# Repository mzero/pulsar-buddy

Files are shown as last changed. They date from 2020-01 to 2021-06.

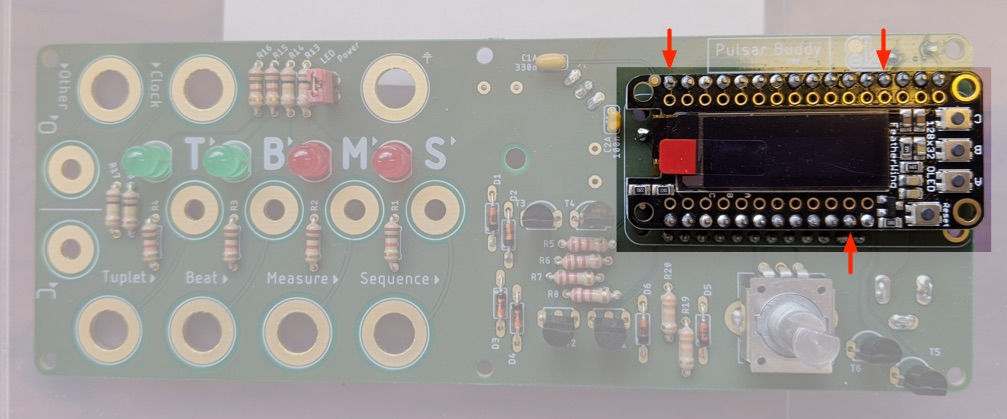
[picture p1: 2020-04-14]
wiki-images/assembly/step 5 top.jpg

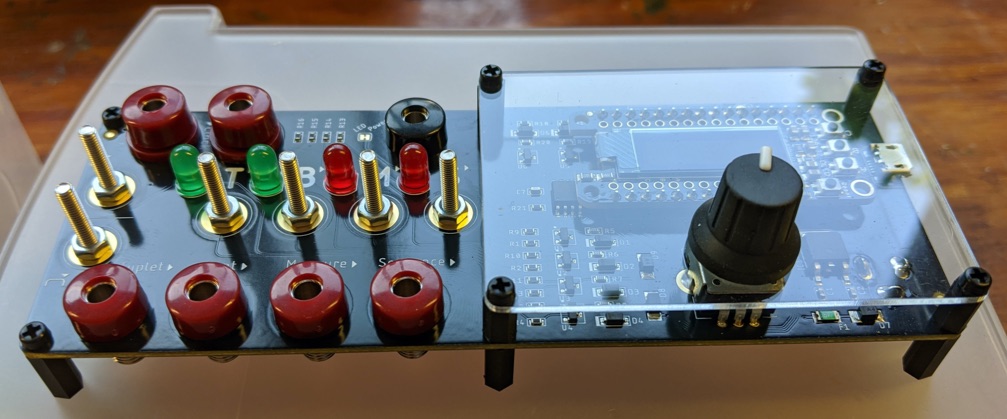
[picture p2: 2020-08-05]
wiki-images/assembly/E step 4 plate.jpg

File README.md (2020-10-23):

# Pulsar Buddy

Pulsar Buddy is a small clock unit for the SOMA Lab's Pulsar-23 synth.
It is also useful with other modular synths.

Please see the [Wiki](https://github.com/mzero/pulsar-buddy/wiki) for full
information.

----

Pulsar Buddy is open source hardware and open source software.

The hardware is licensed by CC-SA-3.0. See LICENSE-HW.txt
The software is licensed by BSD3. See LICENSE-SW.txt

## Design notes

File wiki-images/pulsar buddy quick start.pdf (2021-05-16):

# Here is your

Pulsar Buddy.

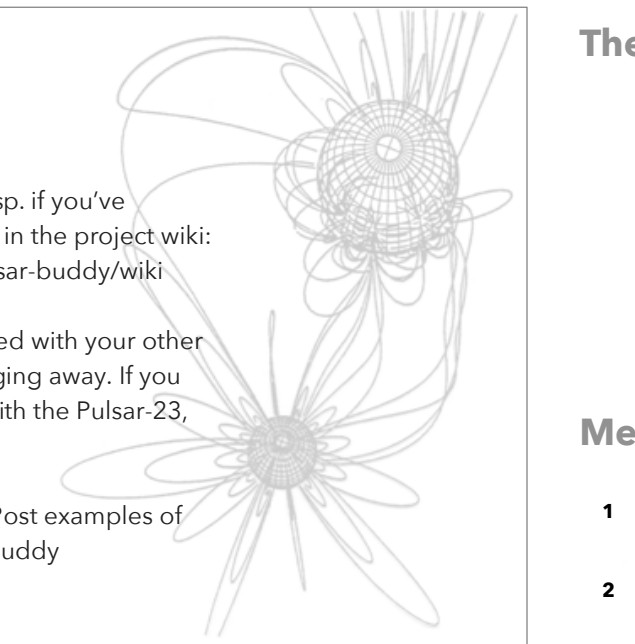
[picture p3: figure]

### It should be pretty self-evident, esp. if you’ve watched the video. The manual is in the project wiki: https://github.com/mzero/pulsar-buddy/wiki

### Make sure that the unit is grounded with your other equipment before you start plugging away. If you

use the included power splitter with the Pulsar-23, then you are good to go.

### Please let me know how it goes. Post examples of you playing with it using #pulsarbuddy

### I can’t wait to hear what you do!

# The Display

Current BPM

Measures in the sequence.
The S output triggers once per sequence.

Time signature.
The M output triggers
once per measure.

Tuplet ratio n:m.
The T output
triggers n times for
every m beats.

Tuplet base beat.
The B output
triggers once for
each base beat.

Memory slots

# Meter & Tuplets

Turn to select
a field.

Click to edit it.

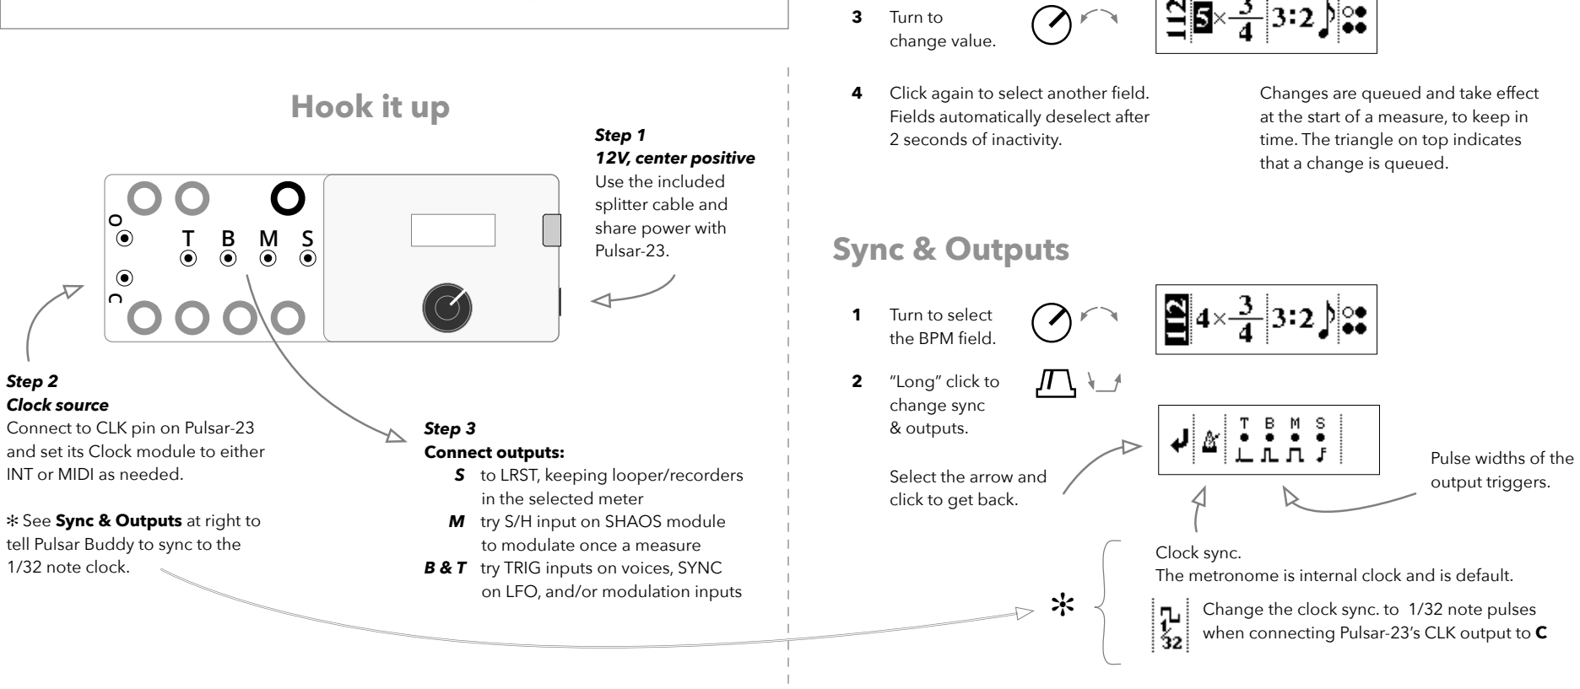
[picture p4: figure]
Hook it up; Step 1 12V, center positive Use the included splitter cable and share power with Pulsar-23.; Step 2 Clock source Connect to CLK pin on Pulsar-23 and set its Clock module to either INT or MIDI as needed.; ✻ See Sync & Outputs at right to tell Pulsar Buddy to sync to the 1/32 note clock.; Step 3 Connect outputs: S to LRST, keeping looper/recorders in the selected meter M try S/H input on SHAOS module to modulate once a measure B & T try TRIG inputs on voices, SYNC on LFO, and/or modulation inputs; Turn to change value.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

Change the clock sync. to 1/32 note pulses when connecting Pulsar-23’s CLK output to C

The metronome is internal clock and is default.

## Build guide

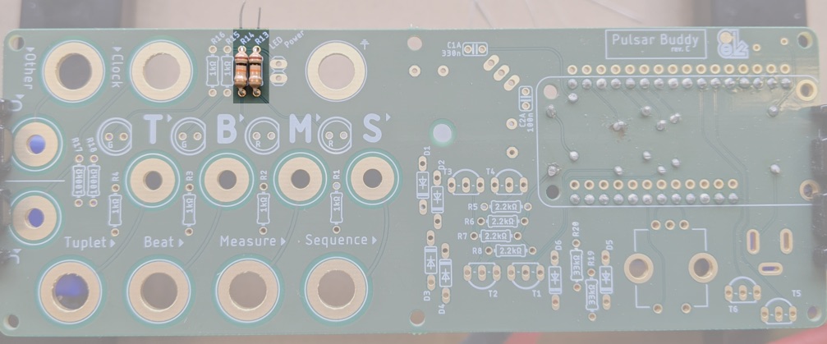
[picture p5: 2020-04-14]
wiki-images/assembly/step 1 top.jpg

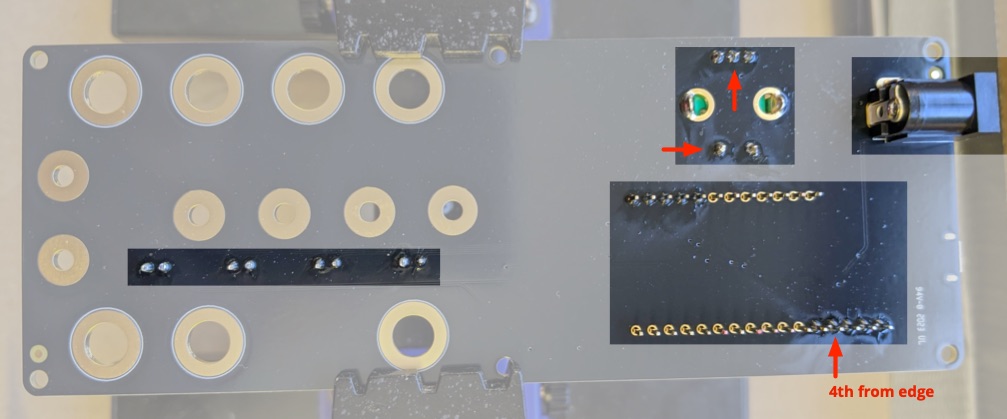
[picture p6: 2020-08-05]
wiki-images/assembly/E step 1 bottom.jpg

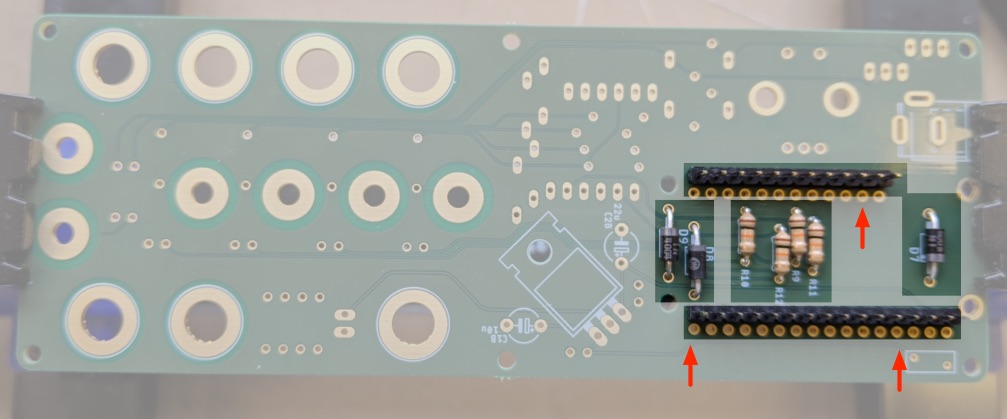
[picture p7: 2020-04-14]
wiki-images/assembly/step 1 bottom.jpg

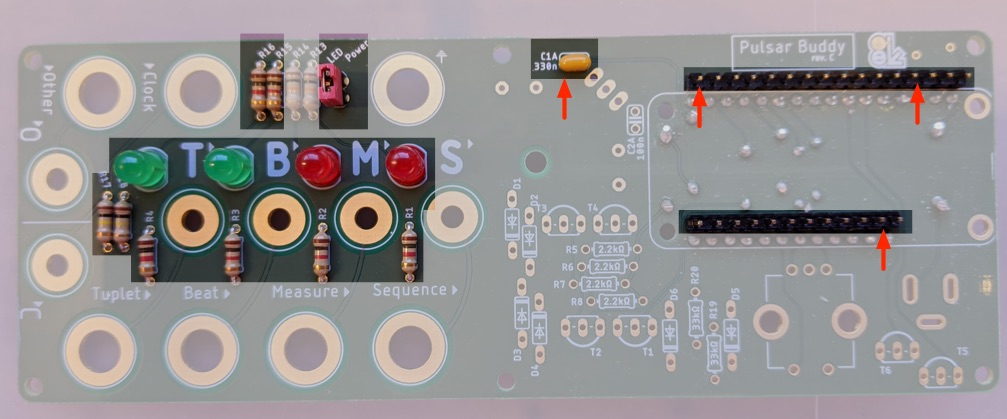
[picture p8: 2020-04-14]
wiki-images/assembly/step 2 top.jpg

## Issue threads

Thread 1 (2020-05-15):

Checking interest form

davispolito, 2020-05-15:
Hi, I believe I submitted an interest form awhile back but just wanted to check and make sure because I haven’t received any update email.

My email is davispolito1@gmail.com
Thanks!

mzero, 2020-05-15:
No problem! You are on the list - I've been really behind, the recent
response has been a bit overwhelming! Enough so that I've got to go set up
a mailing list account, etc...!  I'll try to get a status e-mail out this
week. In short - first batch is totally sold out (yay!) - and I'm trying to
get boards to the fabrication house ASAP so that we'll have a second batch
by early Summer - say mid-July.

- Mark

On Thu, May 14, 2020 at 5:26 PM davispolito <notifications@github.com>
wrote:

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

davispolito, 2020-05-15:
Well I bet that’s great news! I’m glad the project is going well. I love
the emphasis the pulsar puts on weird rhythms and stuff. I look forward to
getting mine and pairing it with the subharmonicon and your pulsar buddy!

How long have you been working with electronics ?

On Thu, May 14, 2020 at 11:04 PM Mark Lentczner <notifications@github.com>
wrote:

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

Closed 2020-05-17.

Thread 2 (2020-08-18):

Shop Link on Wiki is not working

m-r-m-s, 2020-08-18:
Hey hey - just a heads up that the shop link on the wiki is not working:
https://github.com/mzero/pulsar-buddy/wiki

"If you want to buy kits or fully assembled units from me, visit: https://show.electric.kitchen/"

mzero, 2020-08-18:
Thanks for spotting that! Fixed.
The correct url is https://shop.electric.kitchen/

m-r-m-s, 2020-08-18:
Sure thing!

Closed 2020-08-18.

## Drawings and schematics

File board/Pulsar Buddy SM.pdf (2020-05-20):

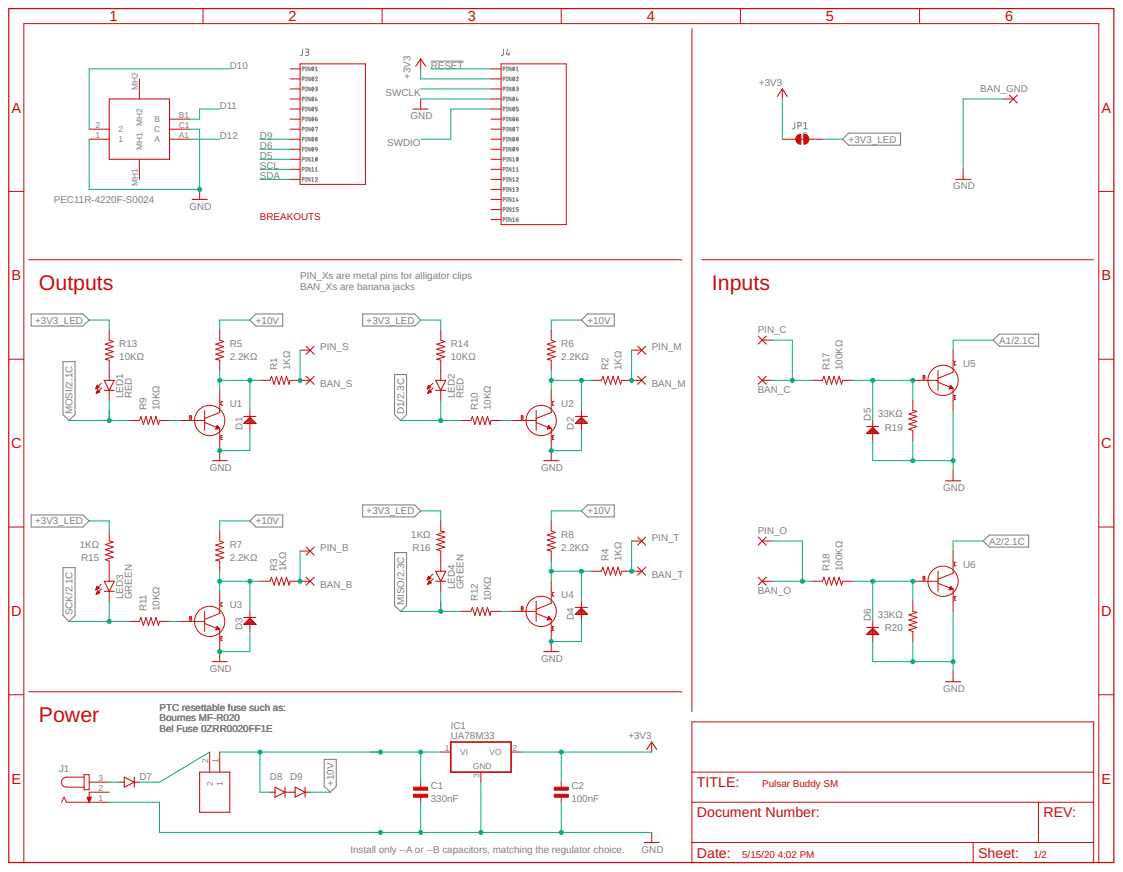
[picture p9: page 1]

PIN_Xs are metal pins for alligator clips BAN_Xs are banana jacks

PTC resettable fuse such as: Bournes MF-R020

Document Number: | REV:

Install only --A or --B capacitors, matching the regulator choice.

Date: 5/15/20 4:02 PM | Sheet: 1/2

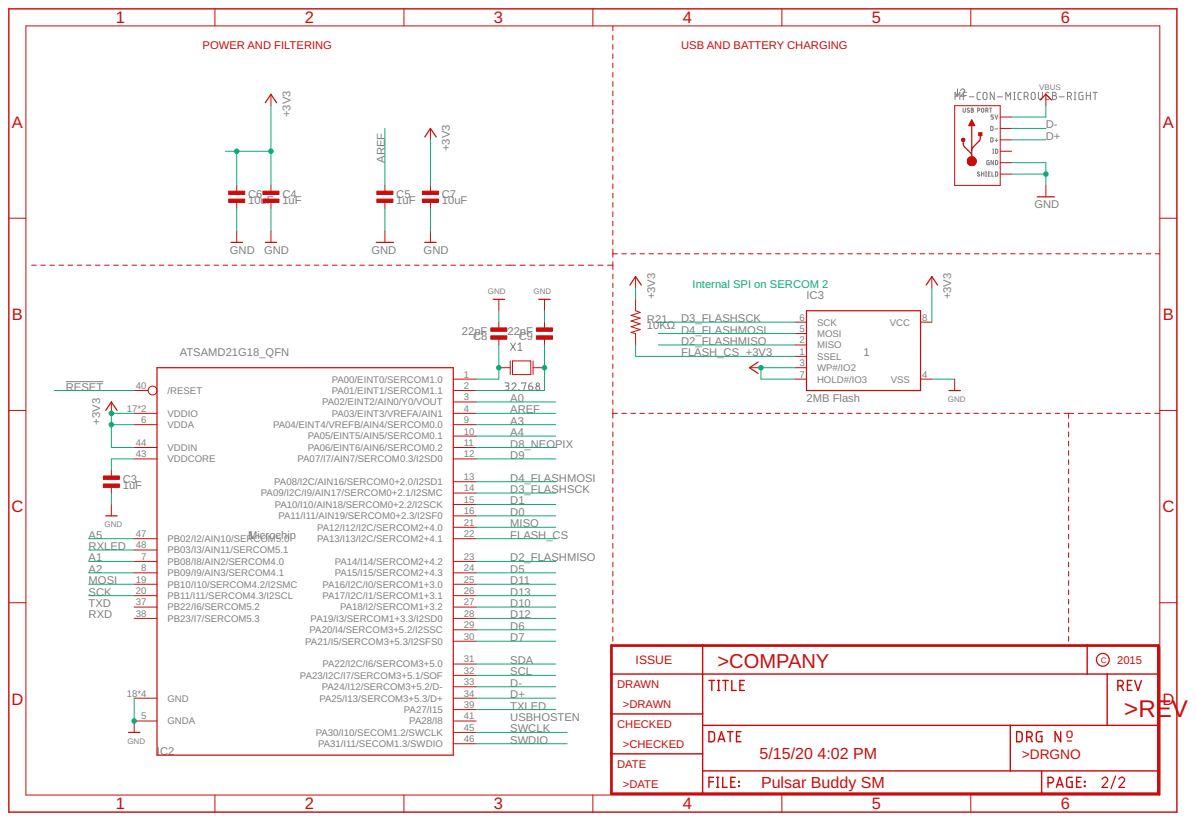
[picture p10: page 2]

Internal SPI on SERCOM 2

ISSUE | >COMPANY | C 2015

DRAWN >DRAWN

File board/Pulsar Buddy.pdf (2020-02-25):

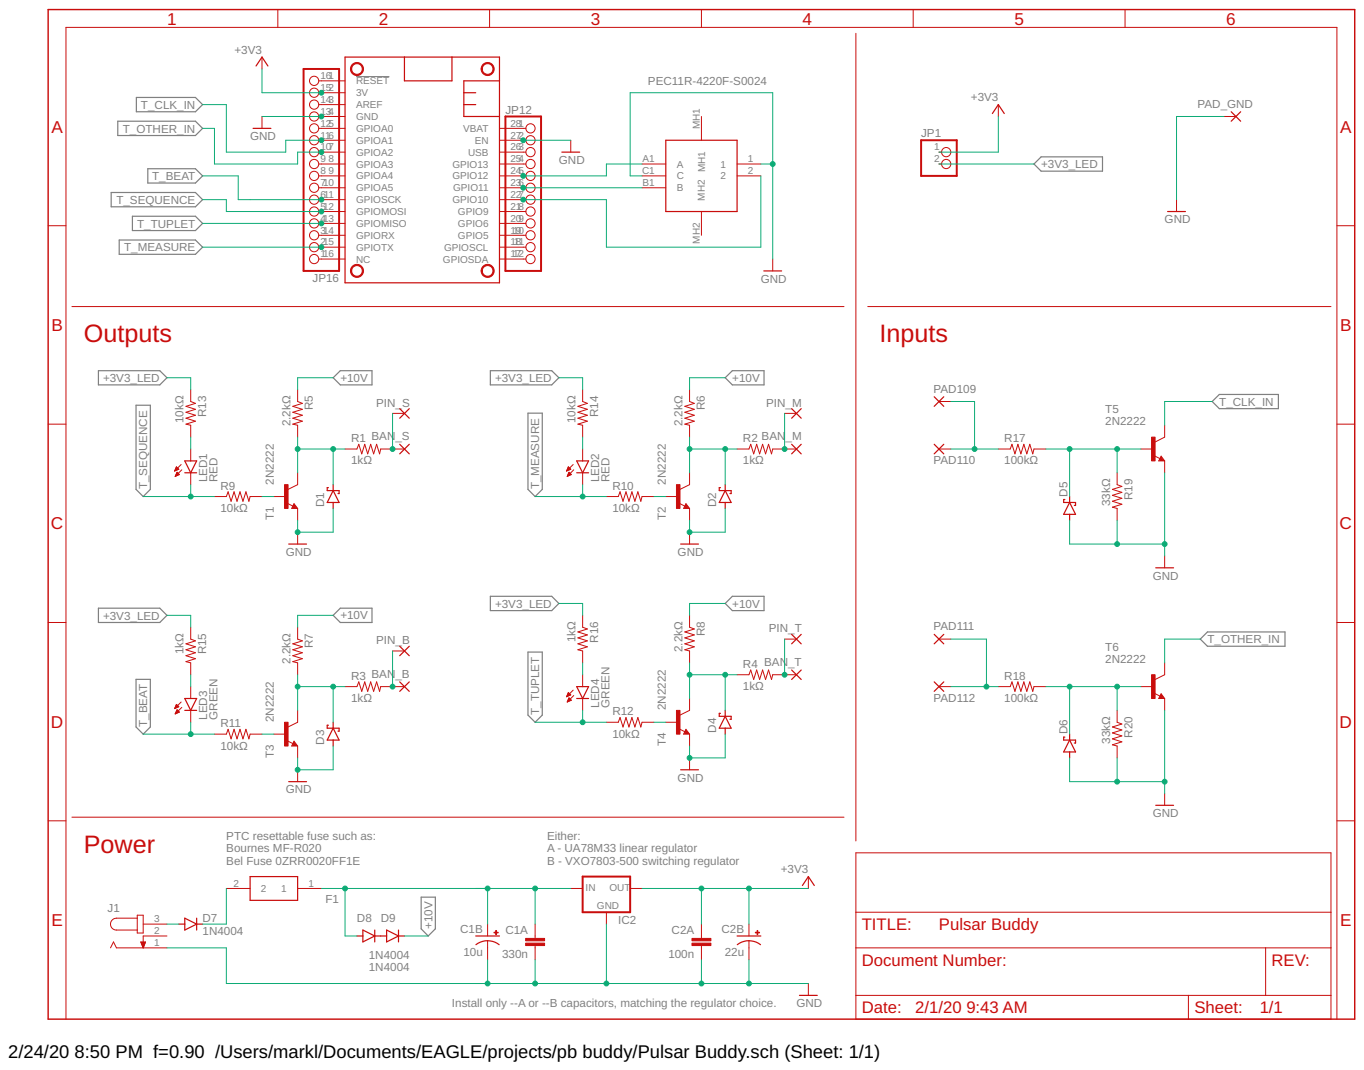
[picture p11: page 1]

PTC resettable fuse such as: Bournes MF-R020 Bel Fuse 0ZRR0020FF1E

Either: A - UA78M33 linear regulator B - VXO7803-500 switching regulator

Document Number: | REV:

Install only --A or --B capacitors, matching the regulator choice.

Date: 2/1/20 9:43 AM | Sheet: 1/1

2/24/20 8:50 PM f=0.90 /Users/markl/Documents/EAGLE/projects/pb buddy/Pulsar Buddy.sch (Sheet: 1/1)

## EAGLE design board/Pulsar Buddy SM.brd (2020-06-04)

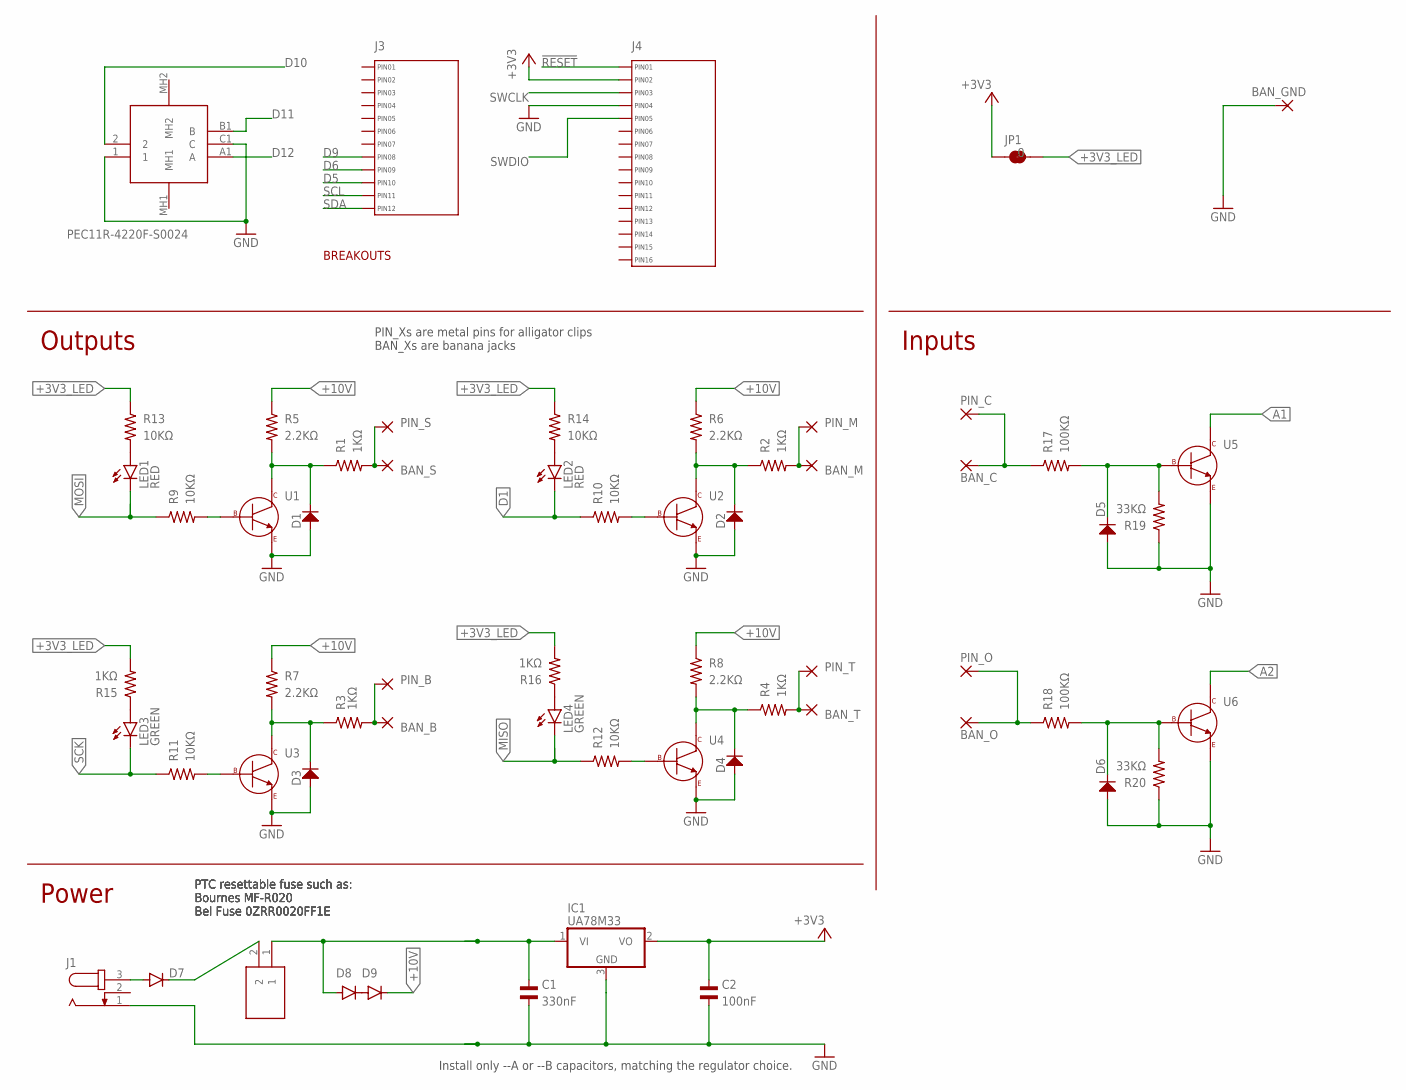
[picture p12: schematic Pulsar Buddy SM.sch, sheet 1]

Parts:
BAN_B: WIREPADBANANA; BANANA
BAN_C: WIREPADBANANA; BANANA
BAN_GND: WIREPADBANANA-GND; BANANA-GND
BAN_M: WIREPADBANANA; BANANA
BAN_O: WIREPADBANANA; BANANA
BAN_S: WIREPADBANANA; BANANA
BAN_T: WIREPADBANANA; BANANA
C1: 330nF; C0603; MPN CC0603ZRY5V7BB334
C2: 100nF; C0603; MPN CC0603KRX7R9BB104
D1, D2, D3, D4, D5, D6: MF-DIO-SOD123-BAT42; SOD-123
D7, D8, D9: CGRM4004-G; SOD-123_MINI-SMA; MPN CGRM4004-G
F1: 0ZCJ0020FF2E; FUSC3216X75N; MPN 0ZCJ0020FF2E
IC1: UA78M33; TO252; MPN UA78M33CKVURG3
J1: JACK-PLUG0; SPC4077
J3: MF-CON-2.54mm-01x12; PTH_2.54MM_01X12
J4: MF-CON-2.54mm-01x16; PTH_2.54MM_01X16
JP1: JUMPER-SMT_2_NC_TRACE_SILK; SMT-JUMPER_2_NC_TRACE_SILK
LED1, LED2: RED; LED5MM
LED3, LED4: GREEN; LED5MM
PIN_B: WIREPAD; M3
PIN_C: WIREPAD; M3
PIN_M: WIREPAD; M3
PIN_O: WIREPAD; M3
PIN_S: WIREPAD; M3
PIN_T: WIREPAD; M3
R1, R2, R3, R4, R15, R16: 1KΩ; R0603; MPN MF-RES-0603-1K
R5, R6, R7, R8: 2.2KΩ; R0603; MPN RC0603JR-072K2L
R9, R10, R11, R12, R13, R14: 10KΩ; R0603; MPN MF-RES-0603-10K
R17, R18: 100KΩ; R0603; MPN MF-RES-0603-100K
R19, R20: 33KΩ; R0603; MPN RC0603FR-0733KL
SW1: PEC11R-4220F-S0024; PEC11R4220FS0024; MPN PEC11R-4220F-S0024
U1, U2, U3, U4, U5, U6: MF-DSC-SOT233-MMBT3904; SOT-23-3

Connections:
!RESET: J4.P$1 (PIN1); also elsewhere on the board
+3V3: C2.P$1, IC1.2 (VO), J4.P$2 (PIN2), JP1.1; also elsewhere on the board
+3V3_LED: JP1.2, R13.P$1, R14.P$1, R15.P$2, R16.P$2
+10V: D9.C, R5.P$1, R6.P$1, R7.P$1, R8.P$1
+12V: C1.P$1, D8.A, F1.1, IC1.1 (VI)
A1: U5.P$3 (COLLECTOR); also elsewhere on the board
A2: U6.P$3 (COLLECTOR); also elsewhere on the board
D1: LED2.K (C), R10.P$1; also elsewhere on the board
D5: J3.P$10 (PIN10); also elsewhere on the board
D6: J3.P$9 (PIN9); also elsewhere on the board
D9: J3.P$8 (PIN8); also elsewhere on the board
D10: SW1.2; also elsewhere on the board
D11: SW1.B1 (B); also elsewhere on the board
D12: SW1.A1 (A); also elsewhere on the board
GND: BAN_GND.C, C1.P$2, C2.P$2, D1.ANODE, D2.ANODE, D3.ANODE, D4.ANODE, D5.ANODE, D6.ANODE, IC1.3 (GND), J1.1, J4.P$4 (PIN4), R19.P$1, R20.P$1, SW1.1, SW1.C1 (C), U1.P$2 (EMITTER), U2.P$2 (EMITTER), U3.P$2 (EMITTER), U4.P$2 (EMITTER), U5.P$2 (EMITTER), U6.P$2 (EMITTER); also elsewhere on the board
MISO: LED4.K (C), R12.P$1; also elsewhere on the board
MOSI: LED1.K (C), R9.P$1; also elsewhere on the board
unnamed: R10.P$2, U2.P$1 (BASE)
unnamed: D7.C, F1.2
unnamed: D7.A, J1.3
unnamed: LED1.A, R13.P$2
unnamed: LED2.A, R14.P$2
unnamed: R9.P$2, U1.P$1 (BASE)
unnamed: D1.CATHODE, R1.P$1, R5.P$2, U1.P$3 (COLLECTOR)
unnamed: D2.CATHODE, R2.P$1, R6.P$2, U2.P$3 (COLLECTOR)
unnamed: LED3.A, R15.P$1
unnamed: R11.P$2, U3.P$1 (BASE)
unnamed: D3.CATHODE, R3.P$1, R7.P$2, U3.P$3 (COLLECTOR)
unnamed: LED4.A, R16.P$1
unnamed: R12.P$2, U4.P$1 (BASE)
unnamed: D4.CATHODE, R4.P$1, R8.P$2, U4.P$3 (COLLECTOR)
unnamed: D5.CATHODE, R17.P$2, R19.P$2, U5.P$1 (BASE)
unnamed: BAN_O.C, PIN_O.1, R18.P$1
unnamed: BAN_C.C, PIN_C.1, R17.P$1
unnamed: D6.CATHODE, R18.P$2, R20.P$2, U6.P$1 (BASE)
unnamed: D8.C, D9.A
unnamed: BAN_S.C, PIN_S.1, R1.P$2
unnamed: BAN_M.C, PIN_M.1, R2.P$2
unnamed: BAN_T.C, PIN_T.1, R4.P$2
unnamed: BAN_B.C, PIN_B.1, R3.P$2
SCK: LED3.K (C), R11.P$1; also elsewhere on the board
SCL: J3.P$11 (PIN11); also elsewhere on the board
SDA: J3.P$12 (PIN12); also elsewhere on the board
SWCLK: J4.P$3 (PIN3); also elsewhere on the board
SWDIO: J4.P$5 (PIN5); also elsewhere on the board

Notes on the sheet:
Inputs
Power
Outputs
Install only --A or --B capacitors, matching the regulator choice.
PTC resettable fuse such as: Bournes MF-R020 Bel Fuse 0ZRR0020FF1E
BREAKOUTS
PIN_Xs are metal pins for alligator clips BAN_Xs are banana jacks

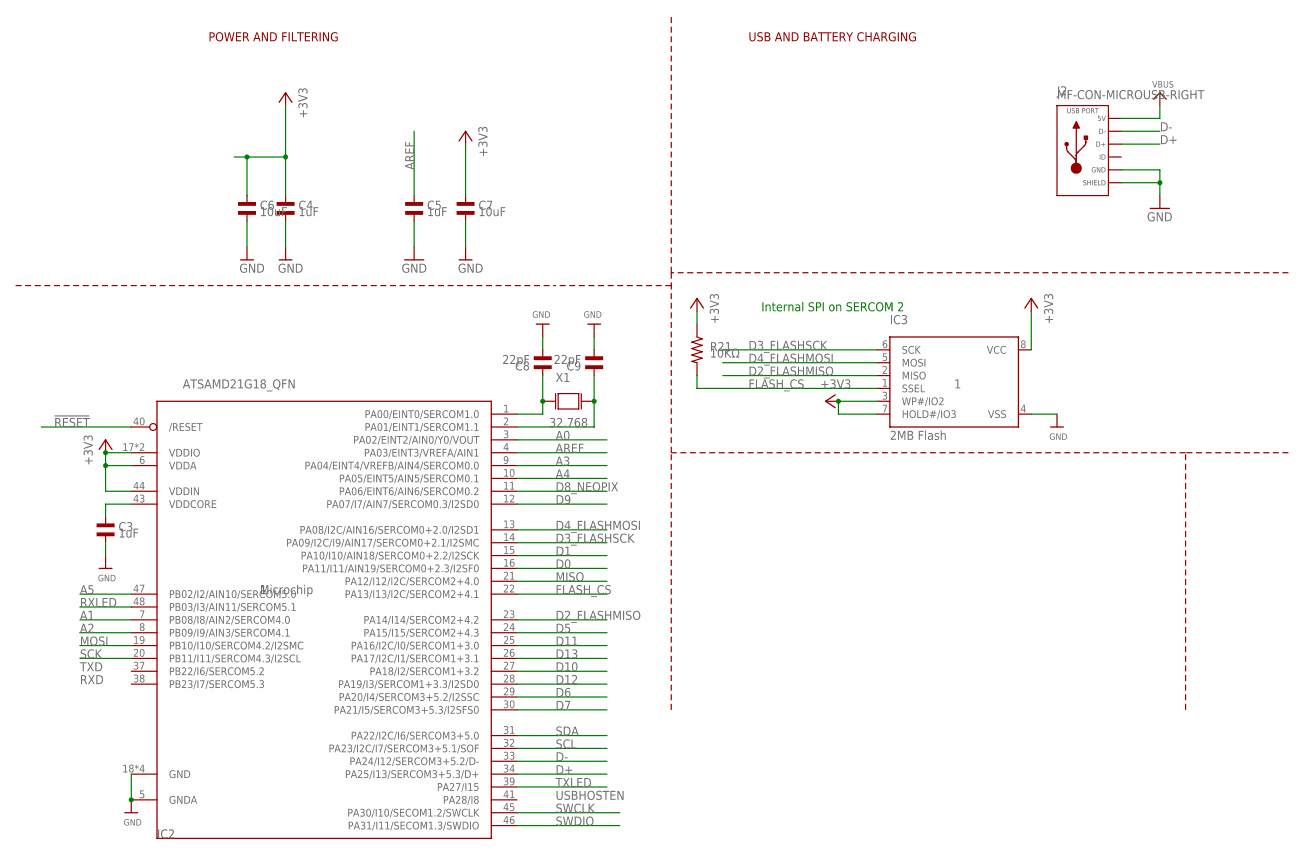
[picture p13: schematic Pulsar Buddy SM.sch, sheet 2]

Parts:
C3, C4, C5: 1uF; C0603; MPN MF-CAP-0603-1uF
C6, C7: 10uF; C0603; MPN 0603ZD106KAT2A
C8, C9: 22pF; C0603; MPN MF-CAP-0603-22pF
IC2: ATSAMD21G18_QFN; TQFN48_7MM; MPN SAMD21G18A-MU
IC3: 2MB Flash; SOIC8_208MIL; MPN S25FL064LABMFI010
J2: MF-CON-MICROUSB-RIGHT; MICROUSB-RIGHT
R21: 10KΩ; R0603; MPN MF-RES-0603-10K
U$34, U$35: FIDUCIAL_100MIL
X1: 32.768; ECX-31B_SERIES; MPN ECS-.327-7-12-C-TR

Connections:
!RESET: IC2.40 (/RESET); also elsewhere on the board
+3V3: C4.P$1, C6.P$1, C7.P$1, IC2.6 (VDDA), IC2.17 (VDDIO), IC2.36 (VDDIO), IC2.44 (VDDIN), IC3.3 (WP#/IO2), IC3.7 (HOLD#/IO3), IC3.8 (VCC), R21.P$1; also elsewhere on the board
A0: IC2.3 (PA02/EINT2/AIN0/Y0/VOUT)
A1: IC2.7 (PB08/I8/AIN2/SERCOM4.0); also elsewhere on the board
A2: IC2.8 (PB09/I9/AIN3/SERCOM4.1); also elsewhere on the board
A3: IC2.9 (PA04/EINT4/VREFB/AIN4/SERCOM0.0)
A4: IC2.10 (PA05/EINT5/AIN5/SERCOM0.1)
A5: IC2.47 (PB02/I2/AIN10/SERCOM5.0)
AREF: C5.P$1, IC2.4 (PA03/EINT3/VREFA/AIN1)
D0: IC2.16 (PA11/I11/AIN19/SERCOM0+2.3/I2SF0)
D1: IC2.15 (PA10/I10/AIN18/SERCOM0+2.2/I2SCK); also elsewhere on the board
D2_FLASHMISO: IC2.23 (PA14/I14/SERCOM2+4.2), IC3.2 (MISO)
D3_FLASHSCK: IC2.14 (PA09/I2C/I9/AIN17/SERCOM0+2.1/I2SMC), IC3.6 (SCK)
D4_FLASHMOSI: IC2.13 (PA08/I2C/AIN16/SERCOM0+2.0/I2SD1), IC3.5 (MOSI)
D5: IC2.24 (PA15/I15/SERCOM2+4.3); also elsewhere on the board
D6: IC2.29 (PA20/I4/SERCOM3+5.2/I2SSC); also elsewhere on the board
D7: IC2.30 (PA21/I5/SERCOM3+5.3/I2SFS0)
D8_NEOPIX: IC2.11 (PA06/EINT6/AIN6/SERCOM0.2)
D9: IC2.12 (PA07/I7/AIN7/SERCOM0.3/I2SD0); also elsewhere on the board
D10: IC2.27 (PA18/I2/SERCOM1+3.2); also elsewhere on the board
D11: IC2.25 (PA16/I2C/I0/SERCOM1+3.0); also elsewhere on the board
D12: IC2.28 (PA19/I3/SERCOM1+3.3/I2SD0); also elsewhere on the board
D13: IC2.26 (PA17/I2C/I1/SERCOM1+3.1)
D+: IC2.34 (PA25/I13/SERCOM3+5.3/D+), J2.3 (D+)
D-: IC2.33 (PA24/I12/SERCOM3+5.2/D-), J2.2 (D-)
FLASH_CS: IC2.22 (PA13/I13/I2C/SERCOM2+4.1), IC3.1 (SSEL), R21.P$2
GND: C3.P$2, C4.P$2, C5.P$2, C6.P$2, C7.P$2, C8.P$2, C9.P$2, IC2.5 (GNDA), IC2.18 (GND), IC2.35 (GND), IC2.42 (GND), IC2.THERMAL (GND), IC3.4 (VSS), J2.5 (GND), J2.S1 (SLD), J2.S2 (SLD), J2.S3 (SLD), J2.S4 (SLD), J2.S5 (SLD), J2.S6 (SLD); also elsewhere on the board
MISO: IC2.21 (PA12/I12/I2C/SERCOM2+4.0); also elsewhere on the board
MOSI: IC2.19 (PB10/I10/SERCOM4.2/I2SMC); also elsewhere on the board
unnamed: C8.P$1, IC2.1 (PA00/EINT0/SERCOM1.0), X1.P$1 (X0)
unnamed: C9.P$1, IC2.2 (PA01/EINT1/SERCOM1.1), X1.P$2 (X1)
RXLED: IC2.48 (PB03/I3/AIN11/SERCOM5.1)
SCK: IC2.20 (PB11/I11/SERCOM4.3/I2SCL); also elsewhere on the board
SCL: IC2.32 (PA23/I2C/I7/SERCOM3+5.1/SOF); also elsewhere on the board
SDA: IC2.31 (PA22/I2C/I6/SERCOM3+5.0); also elsewhere on the board
SWCLK: IC2.45 (PA30/I10/SECOM1.2/SWCLK); also elsewhere on the board
SWDIO: IC2.46 (PA31/I11/SECOM1.3/SWDIO); also elsewhere on the board
TXLED: IC2.39 (PA27/I15)
VBUS: J2.1 (5V)
VDDCORE1: C3.P$1, IC2.43 (VDDCORE)

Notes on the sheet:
POWER AND FILTERING
USBHOSTEN
TXD
RXD
USB AND BATTERY CHARGING
Internal SPI on SERCOM 2

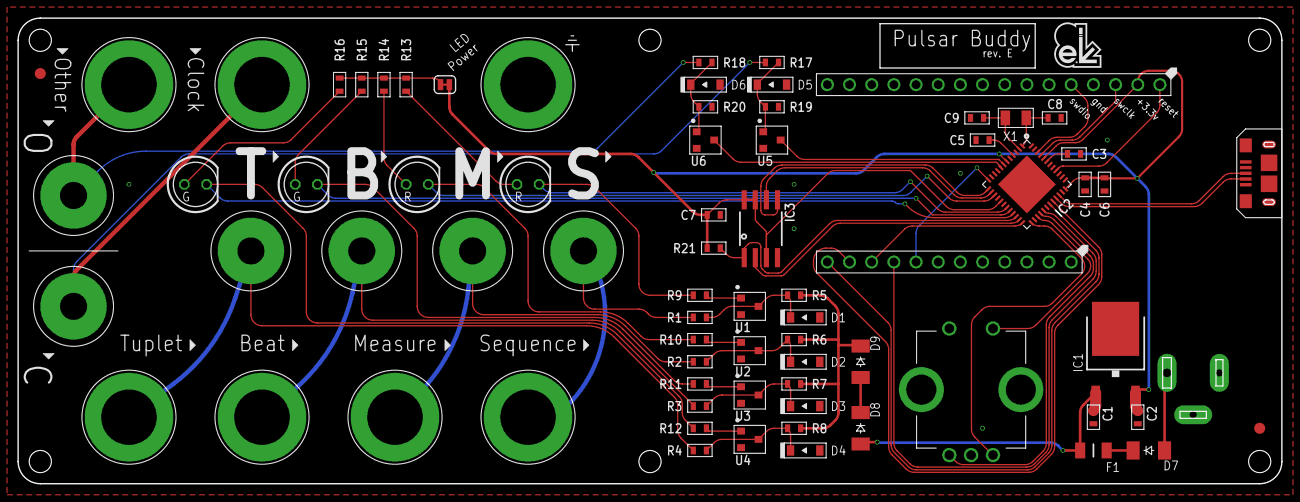
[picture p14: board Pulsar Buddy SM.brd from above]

Board: 2 copper layers, 144.8 x 53.3 mm, 75 parts (1 on the bottom side), 55 nets.

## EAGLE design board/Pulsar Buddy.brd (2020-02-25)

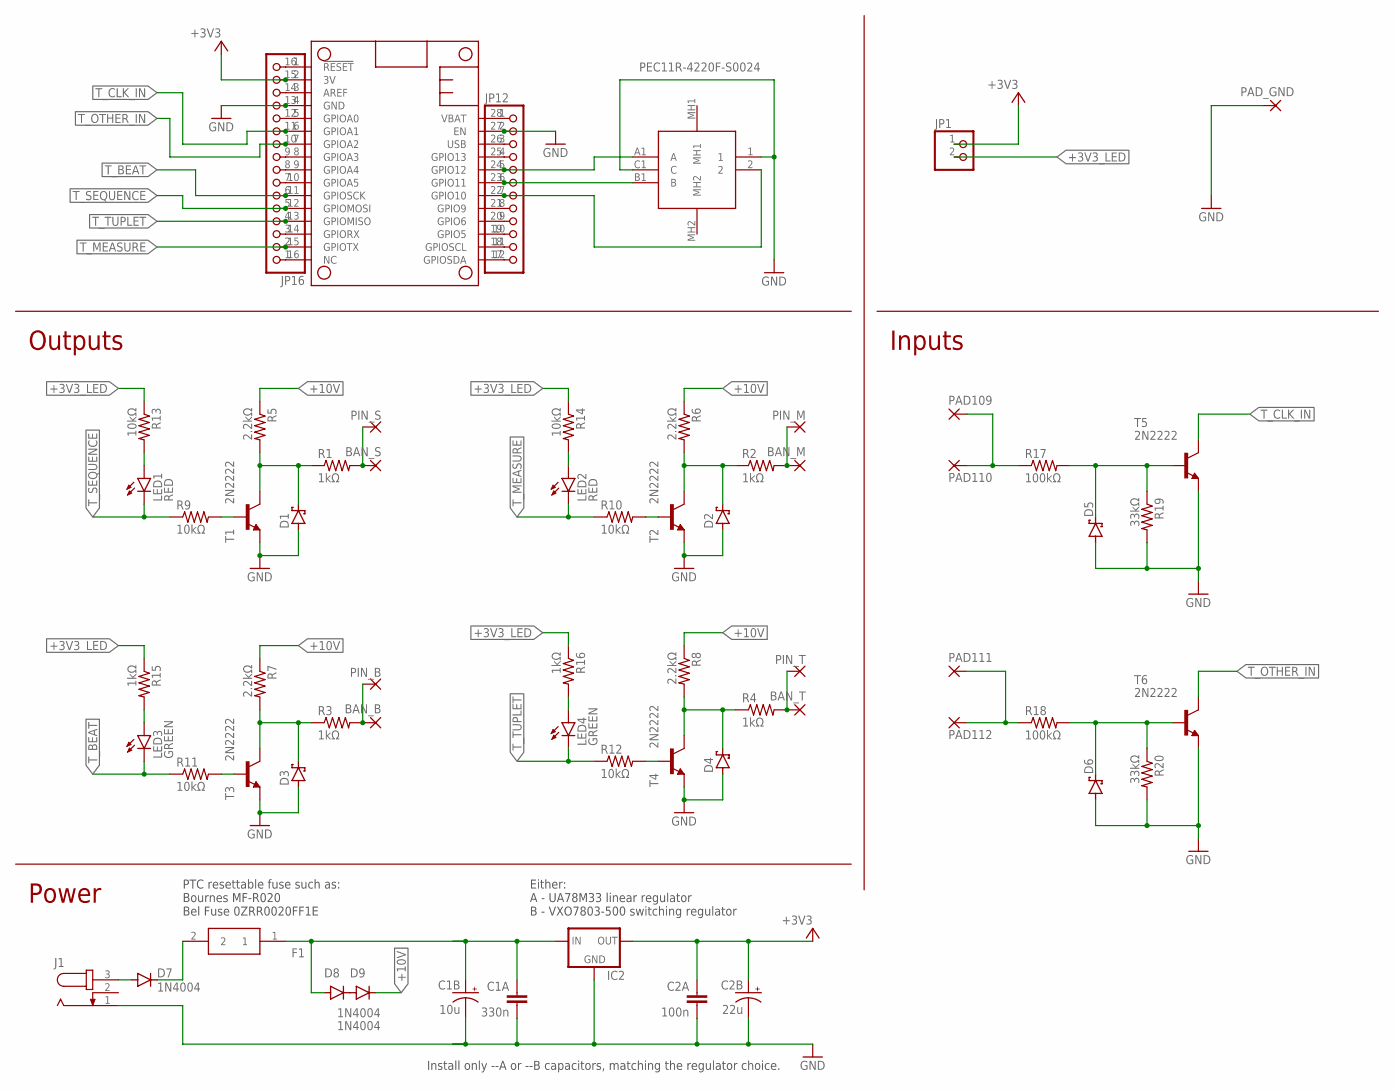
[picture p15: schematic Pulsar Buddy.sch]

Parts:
BAN_B: WIREPADBANANA; BANANA
BAN_M: WIREPADBANANA; BANANA
BAN_S: WIREPADBANANA; BANANA
BAN_T: WIREPADBANANA; BANANA
C1A: 330n; C025-024X044
C1B: 10u; E5-5
C2A: 100n; C025-024X044
C2B: 22u; E5-5
D1, D2, D3, D4, D5, D6: SCHOTTKY-DIODEDO35-7; DO35-7
D7, D8, D9: 1N4004; DO41-10
F1: 0ZRR0025FF1E
IC2: UA78M33CKCSTO-220; TO220H
J1: JACK-PLUG0; SPC4077
JP1: PINHD-1X2; 1X02
JP12: HEADER-1X12; 1X12_ROUND
JP16: HEADER-1X16ROUND; 1X16_ROUND
LED1, LED2: RED; LED5MM
LED3, LED4: GREEN; LED5MM
MS101: FEATHERWING_NODIM; FEATHERWING_DIM
PAD109, PAD111: WIREPAD; M3
PAD110, PAD112: WIREPADBANANA; BANANA
PAD_GND: WIREPADBANANA-GND; BANANA-GND
PIN_B: WIREPAD; M3
PIN_M: WIREPAD; M3
PIN_S: WIREPAD; M3
PIN_T: WIREPAD; M3
R1, R2, R3, R4, R15, R16: 1kΩ; 0204/7
R5, R6, R7, R8: 2.2kΩ; 0204/7
R9, R10, R11, R12, R13, R14: 10kΩ; 0204/7
R17, R18: 100kΩ; 0204/7
R19, R20: 33kΩ; 0204/7
SW1: PEC11R-4220F-S0024; PEC11R4220FS0024
T1, T2, T3, T4, T5, T6: 2N2222; TO92-EBC-OVAL

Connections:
+3V3: C2A.1, C2B.+, IC2.3 (OUT), JP1.1, JP16.15, MS101.2 (3V)
+3V3_LED: JP1.2, R13.1, R14.1, R15.1, R16.1
+5V_CPU: JP12.3, MS101.26 (USB)
+10V: D9.C, R5.1, R6.1, R7.1, R8.1
+12V: C1A.1, C1B.+, D8.A, F1.1, IC2.1 (IN)
GND: C1A.2, C1B.-, C2A.2, C2B.-, D1.A, D2.A, D3.A, D4.A, D5.A, D6.A, IC2.2 (GND), J1.1, JP12.2, JP16.13, MS101.4 (GND), MS101.27 (EN), PAD_GND.C, R19.2, R20.2, SW1.1, SW1.C1 (C), T1.E, T2.E, T3.E, T4.E, T5.E, T6.E
unnamed: JP12.5, MS101.24 (GPIO12), SW1.A1 (A)
unnamed: JP12.7, MS101.22 (GPIO10), SW1.2
unnamed: JP12.6, MS101.23 (GPIO11), SW1.B1 (B)
unnamed: D7.C, F1.2
unnamed: D7.A, J1.3
unnamed: LED1.A, R13.2
unnamed: LED2.A, R14.2
unnamed: R9.2, T1.B
unnamed: D1.C, R1.1, R5.2, T1.C
unnamed: R10.2, T2.B
unnamed: D2.C, R2.1, R6.2, T2.C
unnamed: LED3.A, R15.2
unnamed: R11.2, T3.B
unnamed: D3.C, R3.1, R7.2, T3.C
unnamed: LED4.A, R16.2
unnamed: R12.2, T4.B
unnamed: D4.C, R4.1, R8.2, T4.C
unnamed: D5.C, R17.2, R19.1, T5.B
unnamed: PAD111.1, PAD112.C, R18.1
unnamed: PAD109.1, PAD110.C, R17.1
unnamed: D6.C, R18.2, R20.1, T6.B
unnamed: JP16.16, MS101.1 (!RESET)
unnamed: JP16.14, MS101.3 (AREF)
unnamed: JP16.12, MS101.5 (GPIOA0)
unnamed: JP16.9, MS101.8 (GPIOA3)
unnamed: JP16.8, MS101.9 (GPIOA4)
unnamed: JP16.7, MS101.10 (GPIOA5)
unnamed: JP16.3, MS101.14 (GPIORX)
unnamed: JP16.1, MS101.16 (NC)
unnamed: JP12.12, MS101.17 (GPIOSDA)
unnamed: JP12.11, MS101.18 (GPIOSCL)
unnamed: JP12.10, MS101.19 (GPIO5)
unnamed: JP12.8, MS101.21 (GPIO9)
unnamed: JP12.9, MS101.20 (GPIO6)
unnamed: JP12.4, MS101.25 (GPIO13)
unnamed: D8.C, D9.A
unnamed: BAN_S.C, PIN_S.1, R1.2
unnamed: BAN_M.C, PIN_M.1, R2.2
unnamed: BAN_T.C, PIN_T.1, R4.2
unnamed: BAN_B.C, PIN_B.1, R3.2
T_BEAT: JP16.6, LED3.K (C), MS101.11 (GPIOSCK), R11.1
T_CLK_IN: JP16.11, MS101.6 (GPIOA1), T5.C
T_MEASURE: JP16.2, LED2.K (C), MS101.15 (GPIOTX), R10.1
T_OTHER_IN: JP16.10, MS101.7 (GPIOA2), T6.C
T_SEQUENCE: JP16.5, LED1.K (C), MS101.12 (GPIOMOSI), R9.1
T_TUPLET: JP16.4, LED4.K (C), MS101.13 (GPIOMISO), R12.1
VBAT: JP12.1, MS101.28 (VBAT)

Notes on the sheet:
Inputs
Power
Outputs
Either: A - UA78M33 linear regulator B - VXO7803-500 switching regulator
Install only --A or --B capacitors, matching the regulator choice.
PTC resettable fuse such as: Bournes MF-R020 Bel Fuse 0ZRR0020FF1E

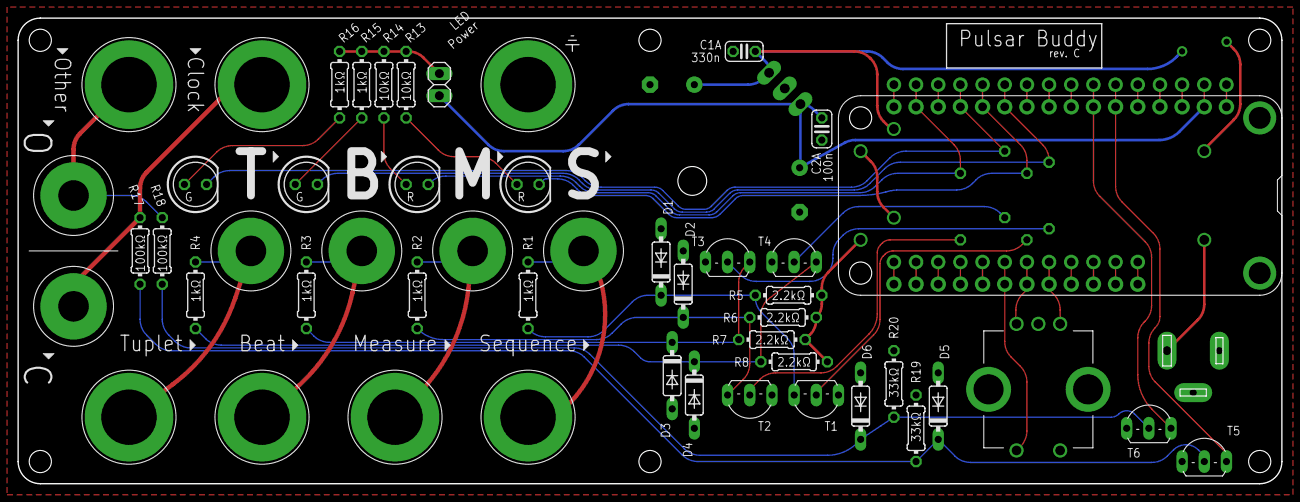
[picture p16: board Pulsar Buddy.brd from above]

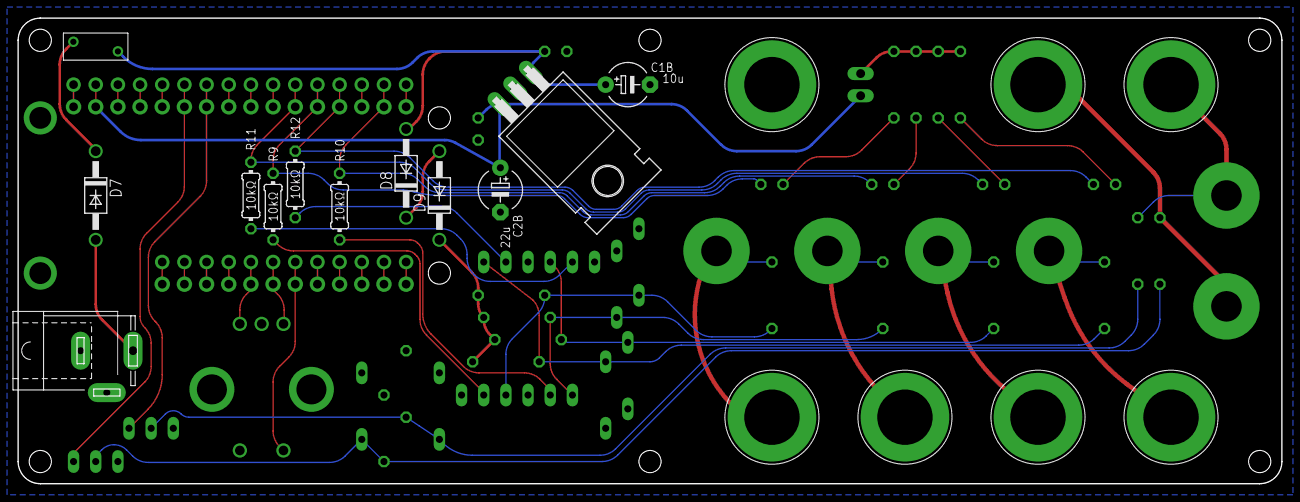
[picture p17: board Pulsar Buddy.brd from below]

Board: 2 copper layers, 144.8 x 53.3 mm, 64 parts (12 on the bottom side), 53 nets.

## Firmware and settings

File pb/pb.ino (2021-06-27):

// #include <ZeroRegs.h>

#include "clock.h"
#include "config.h"
#include "controls.h"
#include "critical.h"
#include "display.h"
#include "layout.h"
#include "midi.h"
#include "state.h"
#include "timer_hw.h"


#ifdef ZERO_REGS_H
ZeroRegOptions zeroOpts = { Serial, true };
#endif

volatile bool measureEvent = false;

void isrMeasure() {
  measureEvent = true;
}

volatile bool nextSettingsEvent = false;

void isrNextSettings() {
  nextSettingsEvent = true;
}

extern "C" char* sbrk(int incr);

uint32_t sramUsed() {
  return (uint32_t)(sbrk(0)) - 0x20000000;
}


void setup() {
  auto s0 = sramUsed();

  Serial.begin(115200);
  initializeDisplay();

  initializeMidi();

  Configuration::initialize();
  if (configuration.debug.waitForSerial) {
    display.clearDisplay();
    display.setTextColor(WHITE);
    display.setCursor(0, 0);
    display.print("Waiting for\nserial connection...");
    display.display();

    while (!Serial);
       // wait for native usb, there is a delay in that call
       // so no need for one here
  }

  initializeState();
  initializeTimers();
  initializeClock();

  setBpm(userState().userBpm);
  setSync(userState().syncMode);
  setOtherSync(userState().otherSyncMode);
  setTiming(userState());
  setPosition(0);

  if (configuration.options.alwaysDim)
    display.dim(true);

  if (critical.update() != Critical::active)
    drawAll(true);

  updateSaver(true);
  selectionTimeout.activity();
  dimTimeout.activity();

  auto s1 = sramUsed();
  Serial.printf("sram used: %d static, %d post-init\n", s0, s1);
}


void loop() {
  bool active = false;

  updateMidi();

  auto status = ClockStatus::current();
  bool advancing = status.advancing();
  if (advancing && userState().userBpm != status.bpm) {
    userState().userBpm = status.bpm;
    active = true;
  }
  persistState();

  if (nextSettingsEvent) {
    loadNextMemory();
    nextSettingsEvent = false;
  }

  bool checkPending = measureEvent || !advancing;
  measureEvent = false;

  if (checkPending && pendingState()) {
    setTiming(userState());
    commitState();
    active = true;
  }

  switch (critical.update()) {
    case Critical::inactive: break;
    case Critical::active: return;
    case Critical::closed: drawAll(true); break;
  }

#if 0
  USBMIDI.poll();
  while (USBMIDI.available()) {
    auto b = USBMIDI.read();

    if (b == 0xf8) {
      midiClock();

      static bool reported = false;
      if (!reported) {
        Serial.println("MIDI clock detected");
        reported = true;
      }
    }
  }
#endif

  auto update = encoder.update();
  if (update.active()) {
    updateSelection(update);
    active = true;
  }

  Button::State s = encoderButton.update();
  if (s != Button::NoChange) {
    clickSelection(s);
    active = true;
  }

  if (encoderButton.active()) {
    active = true;
  }

  if (oledButtonA.update() == Button::Down) {
    dumpDisplayPBM(Serial);
    //setTiming(userState());
    //setPosition(0);
    active = true;
  }

  if (oledButtonB.update() == Button::Down) {
#ifdef ZERO_REGS_H
    // printZeroRegs(zeroOpts);
    // printZeroRegTCC(zeroOpts, TCC0, 0);
    printZeroRegGCLK(zeroOpts);
    printZeroRegEVSYS(zeroOpts);
#endif
    //critical.printf("ouch @ %dms\n", millis());
    //critical.println("  something went wrong");
    active = true;
  }

  if (oledButtonC.update() == Button::Down) {
    Serial.println("-------------------------------------------------------");
    dumpTimers();
    dumpClock();
    active = true;
  }

  static unsigned long nextDraw = 0;
  static bool needsDraw = false;

  if (active) {
    selectionTimeout.activity();
    dimTimeout.activity();
    needsDraw = true;
    if (!configuration.options.alwaysDim)
      display.dim(false);
  } else {
    if (selectionTimeout.update()) {
      resetSelection();
      needsDraw = true;
    }
    if (dimTimeout.update()) {
      display.dim(true);
    }
  }

  auto now = millis();
  static bool saverDrawn = false;

  if (needsDraw || now > nextDraw) {
    bool drew = drawAll(false);
    needsDraw = false;
    nextDraw = now + 50;  // redraw 20x a second

    if (drew) {
      if (saverDrawn)
        drawAll(true);    // need to redraw if the saver had been drawn
    }

    if (!configuration.options.saverDisable)
      saverDrawn = updateSaver(drew);
  } else {
    if (!configuration.options.saverDisable)
      saverDrawn = updateSaver(false);
  }
}

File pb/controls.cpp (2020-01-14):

#include "controls.h"

// OLED FeatherWing buttons map to different pins depending on board:
#if defined(ESP8266)
  #define BUTTON_A  0
  #define BUTTON_B 16
  #define BUTTON_C  2
#elif defined(ESP32)
  #define BUTTON_A 15
  #define BUTTON_B 32
  #define BUTTON_C 14
#elif defined(ARDUINO_STM32_FEATHER)
  #define BUTTON_A PA15
  #define BUTTON_B PC7
  #define BUTTON_C PC5
#elif defined(TEENSYDUINO)
  #define BUTTON_A  4
  #define BUTTON_B  3
  #define BUTTON_C  8
#elif defined(ARDUINO_FEATHER52832)
  #define BUTTON_A 31
  #define BUTTON_B 30
  #define BUTTON_C 27
#else // 32u4, M0, M4, nrf52840 and 328p
  #define BUTTON_A  9
  #define BUTTON_B  6
  #define BUTTON_C  5
#endif

#define ENCODER_SW  10
#define ENCODER_A   12
#define ENCODER_B   11


IdleTimeout selectionTimeout(2000);
IdleTimeout dimTimeout(5000);

Encoder encoder(ENCODER_A, ENCODER_B);
Button encoderButton(ENCODER_SW);

Button oledButtonA(BUTTON_A);
Button oledButtonB(BUTTON_B);
Button oledButtonC(BUTTON_C);

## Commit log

2019-11-24 dim timer
    - and some Serial debugging cleanups
2019-11-26 quantum and beat timers!!
2019-11-26 sequence, measure, and tuplet timers!
2019-11-30 circuit and layout files
    [pb circuit.fzz]
2019-11-30 plumb interrupt to main loop on each measure
2019-12-01 button states
2019-12-01 plumb encoder button state to Filed::click() in case the selected field wants it
2019-12-01 improved UI of memory field
    - press on enter is load mode, will preview slots in display
    - long press on enter is save mode, will *not* preview, and chooses storage slot
    - both require click to confirm, times out to no action
2019-12-03 switch to 8bit values for Settings fields
2019-12-04 updated circuit
    [pb circuit.fzz]
2019-12-09 invert outputs as new buffer needs them inverted
    [timer_hw.cpp]
2019-12-11 cleaned up misc. files
    - moved all circuit stuff over to where the hardware layout was done
    [pb circuit.fzz]
2019-12-13 ext clk is seen inverted due to input buffer
    [timer_hw.cpp]
2019-12-13 improve ext clock rate filtering
    - filter over two beats worth of samples
    - separate out target BPM (measured from ext clock, and shown to user)...
    - ...from actual divisor (includes phase correction)
    [pb.ino, timer_hw.cpp]
2019-12-16 Encoder acceleration (and new Encoder::Update type)
2019-12-16 move ButtonState into Button class, so now Button::State
2019-12-17 basic watchdog timer to detect stopped clock
2019-12-19 reworked watchdog with separate quantum events channel
    [clock.cpp, pb.ino, timer_hw.cpp]
2019-12-20 refresh screen 20x a second, even if no UI activity - to ensure that tracked BPM and state are displayed correctly
    [pb.ino]
2019-12-23 adjusted clock filtering threshold for fast movement
2019-12-24 Add Critical error reporting system
    [critical.cpp, pb.ino]
2019-12-24 make flash.cpp faults use new critical error reporting
    - also fix main .ino so that it can display early critical messages
    [flash.cpp, pb.ino]
2020-01-14 got encoder A & B swapped on PCBs
    [controls.cpp]
2020-01-14 rev A board design
    [Pulsar Buddy rev A.brd, Pulsar Buddy rev A.sch]
2020-01-15 add schematic
    [Pulsar Buddy.brd, Pulsar Buddy.sch]
2020-01-16 update box pcb with split feathers and power connector
2020-01-17 fix issues with perplexed state
    - add hysteresis on allowable BPM range
    - restart counters after exiting perplexed
    - use proper reference points for watchdog vs. sequence timer counts
    - refactor isrClockCapture to have sections per clock state
    - added compile time optional debugging counters for ISRs
    - after setting watchdog timer, return current count for use as a reference
    (needed by perplexed state logic)
    [clock.cpp, timer_hw.cpp]
2020-01-17 improve long press behavior
    - shortened the time for long press
    - made it work even if the field is already selected for value editing
    [ui_input.cpp]
2020-01-19 add schematic pdf
2020-02-01 rev B board
    [Pulsar Buddy.brd, Pulsar Buddy.sch]
2020-02-05 redesign
    - added standoffs to pcb object
    - cut out just pins and knob from box top
    - show inner box standing on foot standoffs
2020-02-18 Rev B. boards
    [Pulsar Buddy.brd, Pulsar Buddy.sch]
2020-02-18 redo case in light of new Pulsar-23 measurements.
2020-02-22 box changes
    - pins are 16mm
    - screw heads modeled more accurately
    - bottom standoffs replaced with screw heads
    - when nested, move inner box up into outer box more
2020-02-22 fix display rotation for rev. B & later boards
2020-02-25 rev C. board layout
    [Pulsar Buddy rev A.brd, Pulsar Buddy rev A.sch, Pulsar Buddy.brd]
2020-03-03 Rev C2 boxes
    - center tabs now fill out (as arc intersected them)
    - location of hole for knob fixed
    - box gap increased to 0.75mm per edge
    - power socket access
    - hole for knob shaft in acrylic plate
2020-03-09 console.log plate dimensions
2020-04-09 disable screen shot button
2020-04-10 factored out pin code into new pins.h and pins.cpp
2020-04-14 images of assembly for wiki
2020-05-20 First SMT based board - rev. D
    [Pulsar Buddy SM.brd, Pulsar Buddy SM.sch]
2020-05-20 updated side with connectors to have vents
    - looks cool, even if the SMT board doesn't need venting!
2020-06-03 correctly handle write() return value
    [critical.cpp]
2020-06-03 surface mount Box and plate
2020-06-04 rev. E board (SMT)
    - smaller holes for screw posts
    - minor aesthetic trace layout changes
    [Pulsar Buddy SM.brd, Pulsar Buddy SM.sch]
2020-06-06 Support flash chip used in SMT board
    This requires a pending pull request to the Adafruit_SPIFlash library.
    until that is merged, use the head of the mzero fork of that library on github.
2020-06-27 Add Frame ui class
2020-06-28 Return button class to return to main screen
2020-06-29 re-work types in timing.h to support upcoming changes
    - decoupled the four pin periods & widths from the logical settings of sequence and measure length
    - split out Offsets as its own type
    - 'nextMeasure' field is for upcoming measure compare register on the sequence timer.
2020-06-30 use buffered CC for widths when possible
    - this avoids occasionally very long pulses when the user changes width to very small while it is high
    - not so worrisome for B, which uses a TC that has no buffering for CC - because that must always be a shorter period
    [timer_hw.cpp]
2020-06-30 track measures using sequenceTCC
    - currently just for debugging, keeps old measureTCC measure tracking
    - adds messages so we can see that they are the same
2020-07-12 drop speed of flash to 4MHz to ensure it works on all rev. E boards
    Turns out that the decoupling capacitor for the flash chip, C7, was
    badly laid out, and the return path to GND on the chip is too long.
    This results in ringing on the MISO signal, on most (but not all) rev. E
    boards.
    Full speed (48MHz) and half speed (24MHz) tests result in appreciable
    read errors. At 12MHz, no board to date has any errors. Since the
    amount of reading and writing is actually quite small, setting the
    rate down to 4MHz will have no appreciable effect on the device, and
    should remove any worry about it working on all boards.
    [flash.cpp]
2020-08-05 rev E. assembly images
2020-10-09 don't print while adjusting offsets
    - could be called from interrupts - and then bad things happen!
2020-10-09 small fixes to clock ISR
    [clock.cpp]
2020-10-09 keep track of position in clock
    - use it to compute phase error
    [clock.cpp, timer_hw.cpp]
2020-10-13 massive re-write of clock ISRs
    - unify much of the code so it isn't in a giant switch(clockState)
    - always update sequenceSample if adjusting currentPosition at start of isrClock
    - allow divisors that are very far out of range.... meld them into the capture buffer,
    - they will get evened out
    - handles the crazy timing at the start from non-1/16 note boundaries in Live
    - simplify the phase adjust code
    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
2020-10-22 handle external clocks when explicitly stopped
    - like MIDI devices that send clock when stopped
    - leave quantum running all the time - so that tempo estimation can continue
    - save and restore counts around periods of pause or stopped
2020-10-26 MIDI vid/pid code
    see: https://pid.codes/1209/6F00/
2020-10-26 drop watchdog sample from isrClockCapture
2020-10-26 tuned BPM display
    - made a little more responsive
    - issue with Live starting from odd 32nd note boundry...
    it's better than what you see on the Digitakt, so okay
    [clock.cpp]
2020-10-26 fix output MIDI clock packet
    [midi.cpp]
2020-10-26 initialize MIDI early
    - otherwise, if configuring, then it gets missed as USB comes up
    [pb.ino]
2020-10-26 update pending state when stopped
    - also fix silly bug in clock.h
    [pb.ino]
2020-10-26 added flipped display configuration
    - also improved code for configuration using a field enum
    [config.cpp]
2020-10-27 don't perplex on first sync ext clock
    when captureLastSample isn't valid, dNext won't be computed, and hence out of range
    but if the clock is running and things are sync, then this can because the user changed
    the settings - don't perplex in this case.
    [clock.cpp]
2020-10-27 improve compute order in isrClockCapture
    - qdiff can still be calculated if done before pending sequence or position changes
    - this lets the clock estimation still occur in these cases without skipping a ext. clock
    - position changing code is cleaned up a bit, removing some duplicate code
    - when changing the timing, let the isr handle updating the counts (if it is running)
    [clock.cpp]
2020-10-27 replace ClockMode with simpler bool clockInternal
    - setState() on setSync(), ensuring clock doesn't get stuck in stopped when changing sync from MIDI to something else
    [clock.cpp]
2020-10-28 one more clock overhaul
    - make clockStopped a separate bool, not a ClockState
    - governs if clock advances with ext. clocks or not
    - otherwise, the clock estimation ignores it
    - reset clockStopped when changing sync modes
    - so a MIDI stop doesn't keep things from advancing when changing to another sync mode
    - rename forceTriggersOff to disableTriggers
    - and make responsible for keeping track of state to avoid excess HW register hits
    - cleans up clock code considerably
    - also rename forceOff to disable in pins.h/.cpp
    - add stopped to ClockStatus
    - renamed running() to advancing()
    - display BPM in tiny text if stopped but not paused
    - to the user, display both stopped or clock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
    [clock.cpp, pb.ino, pins.cpp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]
2020-10-28 reset MIDI state when replugging is detected
    [midi.cpp]
2020-10-29 speed up I2C for display
    - seems to work....!
2021-06-19 fix interrupt clearing
    this was the cause of the very occasional missed clock
    [timer_hw.cpp]
2021-06-19 add VSC Arduino configuration and workspace files
    N.B.:
    - c_cpp_properties.json is ignored as the Arduino extension rebuilds it as needed
    - normal work flow will later arduino.json by adding details of your specific serial port in use - don't commit that change
2021-06-22 add readSequenceCount() to timer module
    this is faster than reading all the counts, if it is all we need
2021-06-26 generate interrupts from O pin
2021-06-26 when setting other sync, reset clock stopped state appropriately
    [clock.cpp]
2021-06-28 when switching other sync modes, ensure clock isn't stuck in stopped state
    also - if setting to one of the din/trigger sync modes, start/stop as appropriate
    [clock.cpp]

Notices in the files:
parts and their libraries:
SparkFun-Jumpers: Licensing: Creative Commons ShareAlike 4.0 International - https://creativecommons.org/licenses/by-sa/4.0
